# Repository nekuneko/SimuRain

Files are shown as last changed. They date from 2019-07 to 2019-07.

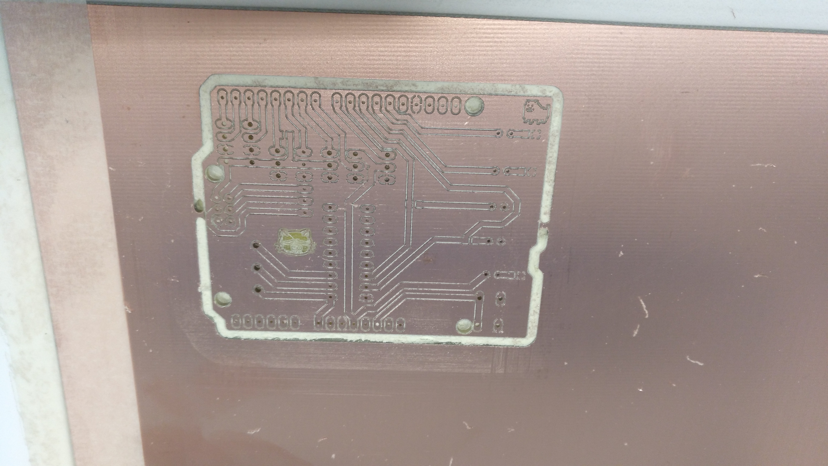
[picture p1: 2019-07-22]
Documentación/Fotos/IMG_20181212_210651_355.jpg

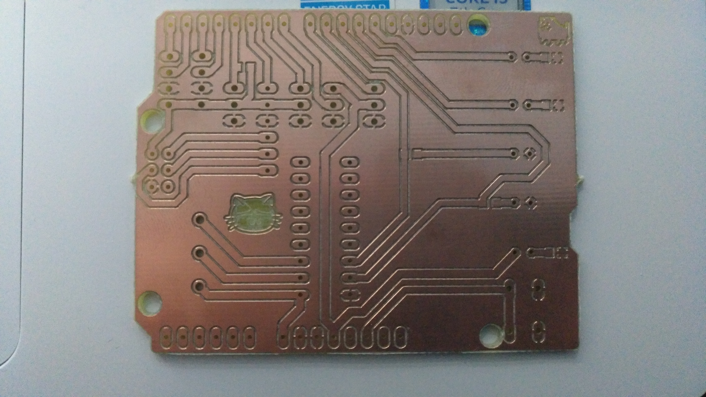
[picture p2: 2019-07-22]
Documentación/Fotos/IMG_20181212_230534_652.jpg

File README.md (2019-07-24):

## Instructions (Work in progress...)

The system currently works following the flow:

* The program is loaded into the ROM of the card and gets activated when receives electric power and the serial port is opened.

* When running, the program writes every 2 second the data received from the different sensors. So running the Arduino IDE showing the serial port is recommended. This information is needed firstly to calibrate the instruments of the experiment.

* Software records day-time, Ph and temperature every two seconds.

* The output file is "datalog.txt", but it can be modified in the source code. It includes Windows CRLF, in UTF-8 format.

* Every time new data is recorded in the microSD card, the modification date of the file in the operating system is modified.

* New data is appended at the end of the file. If user needs data separated into different files, (s)he has to do it manually.

Troubleshooting:

* In case of problems when writing in the card, formatting the SD card with the "SD Card Formatter" software is recommended: https://www.sdcard.org/downloads/formatter_4/index.html

* In case the time is not synchronized (or too early/delayed) it can be re-adjusted: disconnect electric power, take the batteries off using a screwdriver and, after 10 seconds, connect it again and load the program anew. The system, when the serial port will be opened, will detect that there is no actual time and will use the compilation time of the program as current time.

## Instrucciones provisionales (Work in progress...)

El programa actualmente funciona de la siguiente manera:

* El programa se carga en la ROM de la tarjeta y se activa cuando recibe alimentación y se abre el puerto serial. En el puerto serial se van mostrando las lecturas y otra información, por lo que hace falta tener e Arduino IDE y mostrar el puerto serial. Esta información puede servir para la calibración del experimento.

* El software registra dia-hora, Ph y temperatura (no caudal), espera hasta que terminen de pasar 2 segundos y vuelve a hacerlo.

* El nombre del fichero de salida es "datalog.txt", su puede cambiar al inicio del programa. El fichero tiene final de línea Windows CRLF, codificado en UTF-8.

* Cuando se escribe en la tarjeta microSD, se guarda la fecha de modificación de la última vez que fue escrita.

* El contenido se añade al final del fichero. Si se desean separar los datos hay que hacerlo a mano desde el ordenador.

En caso de problemas:

* Si hay problemas de escritura se debe probar a formatear la tarjeta microSD con el software "SD Card Formatter": https://www.sdcard.org/downloads/formatter_4/index.html

* Si se pierde la hora (o el reloj atrasa/adelanta más de lo deseado) se puede ajustar la hora. Para hacerlo se desconecta todo de la alimentación eléctrica, se saca la pila con un destornillador, se esperan 10 segundos, se vuelve a conectar y se vuelve a subir el programa. El sistema, cuando se abra el puerto serial, detectará que no tiene horay cogerá la hora de la última compilación del programa como hora actual para desde ahí empezará a contar.

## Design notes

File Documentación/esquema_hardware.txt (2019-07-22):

El esquema comienza con dos mangueras numeradas 1 (izquierda) y 2 (derecha) que suponen la entrada de líquidos al sistema, cada una controlada con un relé o electroválvula.

El agua se mezcla en una "T" y pasa por el medidor de caudal (caudalímetro), medido de Ph y medidor de temperatura, en ese orden, antes de salir por la alcachofa de la ducha.

Todo está conectado a una placa Arduino Leonardo (parece que la Arduino UNO tiene una memoria insuficiente para el software que necesitamos ejecutar). Sobre esa placa hay una placa de conexión que redirige los pines a los sensores correspondientes. El conexionado actual es el siguiente (NC es No Conectado, no se usa). A veces se indica uso distinto si fuera Leonardo o UNO:

 // Pin configuration
 // Note: By default relays are connected to 12v, so they are CLOSED and they don't permit water flow.
 // pinMode(A5, NC);                  // A5 - Arduino UNO: I2C SCL; Arduino Leonardo: NC
 // pinMode(A4, NC);                  // A4 - Arduino UNO: I2C SDA; Arduino Leonardo: NC
 // pinMode(A3, NC);                  // A3 
 // pinMode(A2, NC);                  // A2 
 // pinMode(A1, NC);                  // A1 
 // pinMode(13, NC);                  // D13                Arduino UNO: SPI SCK;  Arduino Leonardo: NC
    pinMode(PIN_LED_INFO,   OUTPUT);  // D12 - LED INFO     Arduino UNO: SPI MISO; Arduino Leonardo: NC
    pinMode(PIN_LED_STATUS, OUTPUT);  // D11 - LED STATUS   Arduino UNO: SPI MOSI; Arduino Leonardo: NC
    pinMode(PIN_RELAY_1,    OUTPUT);  // D10 - Relay 8B -> ULN2803A Darlington Transistor Array -> 8C -> RIGHT RELAY, WATER INPUT 2: HIGH OPEN; LOW CLOSED
    pinMode(PIN_RELAY_2,    OUTPUT);  // D9  - Relay 7B -> ULN2803A Darlington Transistor Array -> 7C -> LEFT  RELAY, WATER INPUT 1: HIGH OPEN; LOW CLOSED
    pinMode(PIN_SENSOR_AUX,  INPUT);  // D8  - (A8) Sensor: AUX
    pinMode(PIN_SENSOR_FLOW, INPUT_PULLUP);  // D7 - Sensor: Flow (INTERRUPT)
    pinMode(PIN_SENSOR_PH,   INPUT);  // D6 - (A7)Sensor: PH   
 // pinMode(PIN_SDCARD_SS,  OUTPUT);  // D5 - SPI Chipselect: MicroSD, initialized on SD begin function.
 // pinMode(PIN_SENSOR_TEMP, INPUT);  // D4 - (A6) Sensor: Temp, initialized on DS18B20 constructor. 
 // pinMode(3,  NC);                  // D3 - Arduino Leonardo: I2C SCL  
 // pinMode(2,  NC);                  // D2 - Arduino Leonardo: I2C SDA  
 // pinMode(1,  NC);                  // D1 - Arduino Leonardo: Serial1 
 // pinMode(0,  NC);                  // D0 - Arduino Leonardo: Serial1

La interfaz hardware del sistema muestra 5 leds:

	* SISTEMA ENCENDIDO: Este led indica que el sistema está encendido y siempre se iluminará al conectar la alimentación.
	* ENTRADA DE AGUA 1: Este led se iluminará cuando se encuentre abierta la entrada de agua número 1 (izquierda).
	* ENTRADA DE AGUA 2: Este led se iluminará cuando se encuentre abierta la entrada de agua número 2 (derecha).
	* ESTADO: Por determinar, si el arranque va bien se iluminará.
	* INFO: Por determinar, si el arranque es correcto se iluminará.

Dispone de un botón RESET para reiniciar el sistema en lugar de tener que desenchufar la placa y volverla a enchufar.

Medida del caudal:
El caudal se mide por interrupciones, durante un segundo, se leen cuantas vueltas ha realizado el sensor de efecto hall del caudalímetro.

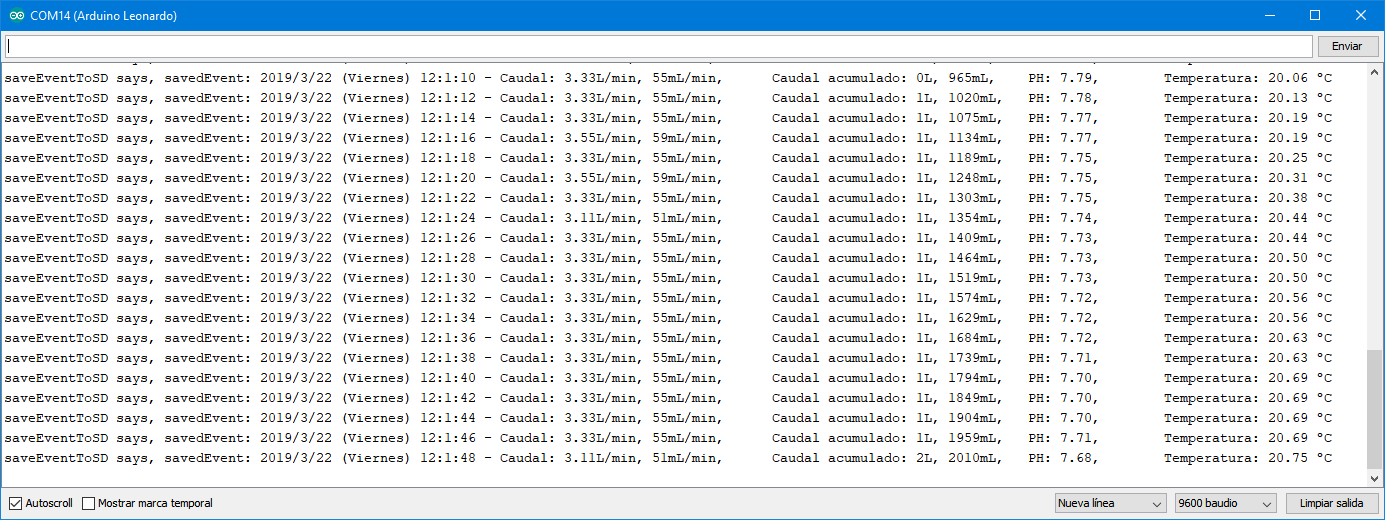
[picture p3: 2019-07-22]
Documentación/Datos recabados/datosLluvia.PNG

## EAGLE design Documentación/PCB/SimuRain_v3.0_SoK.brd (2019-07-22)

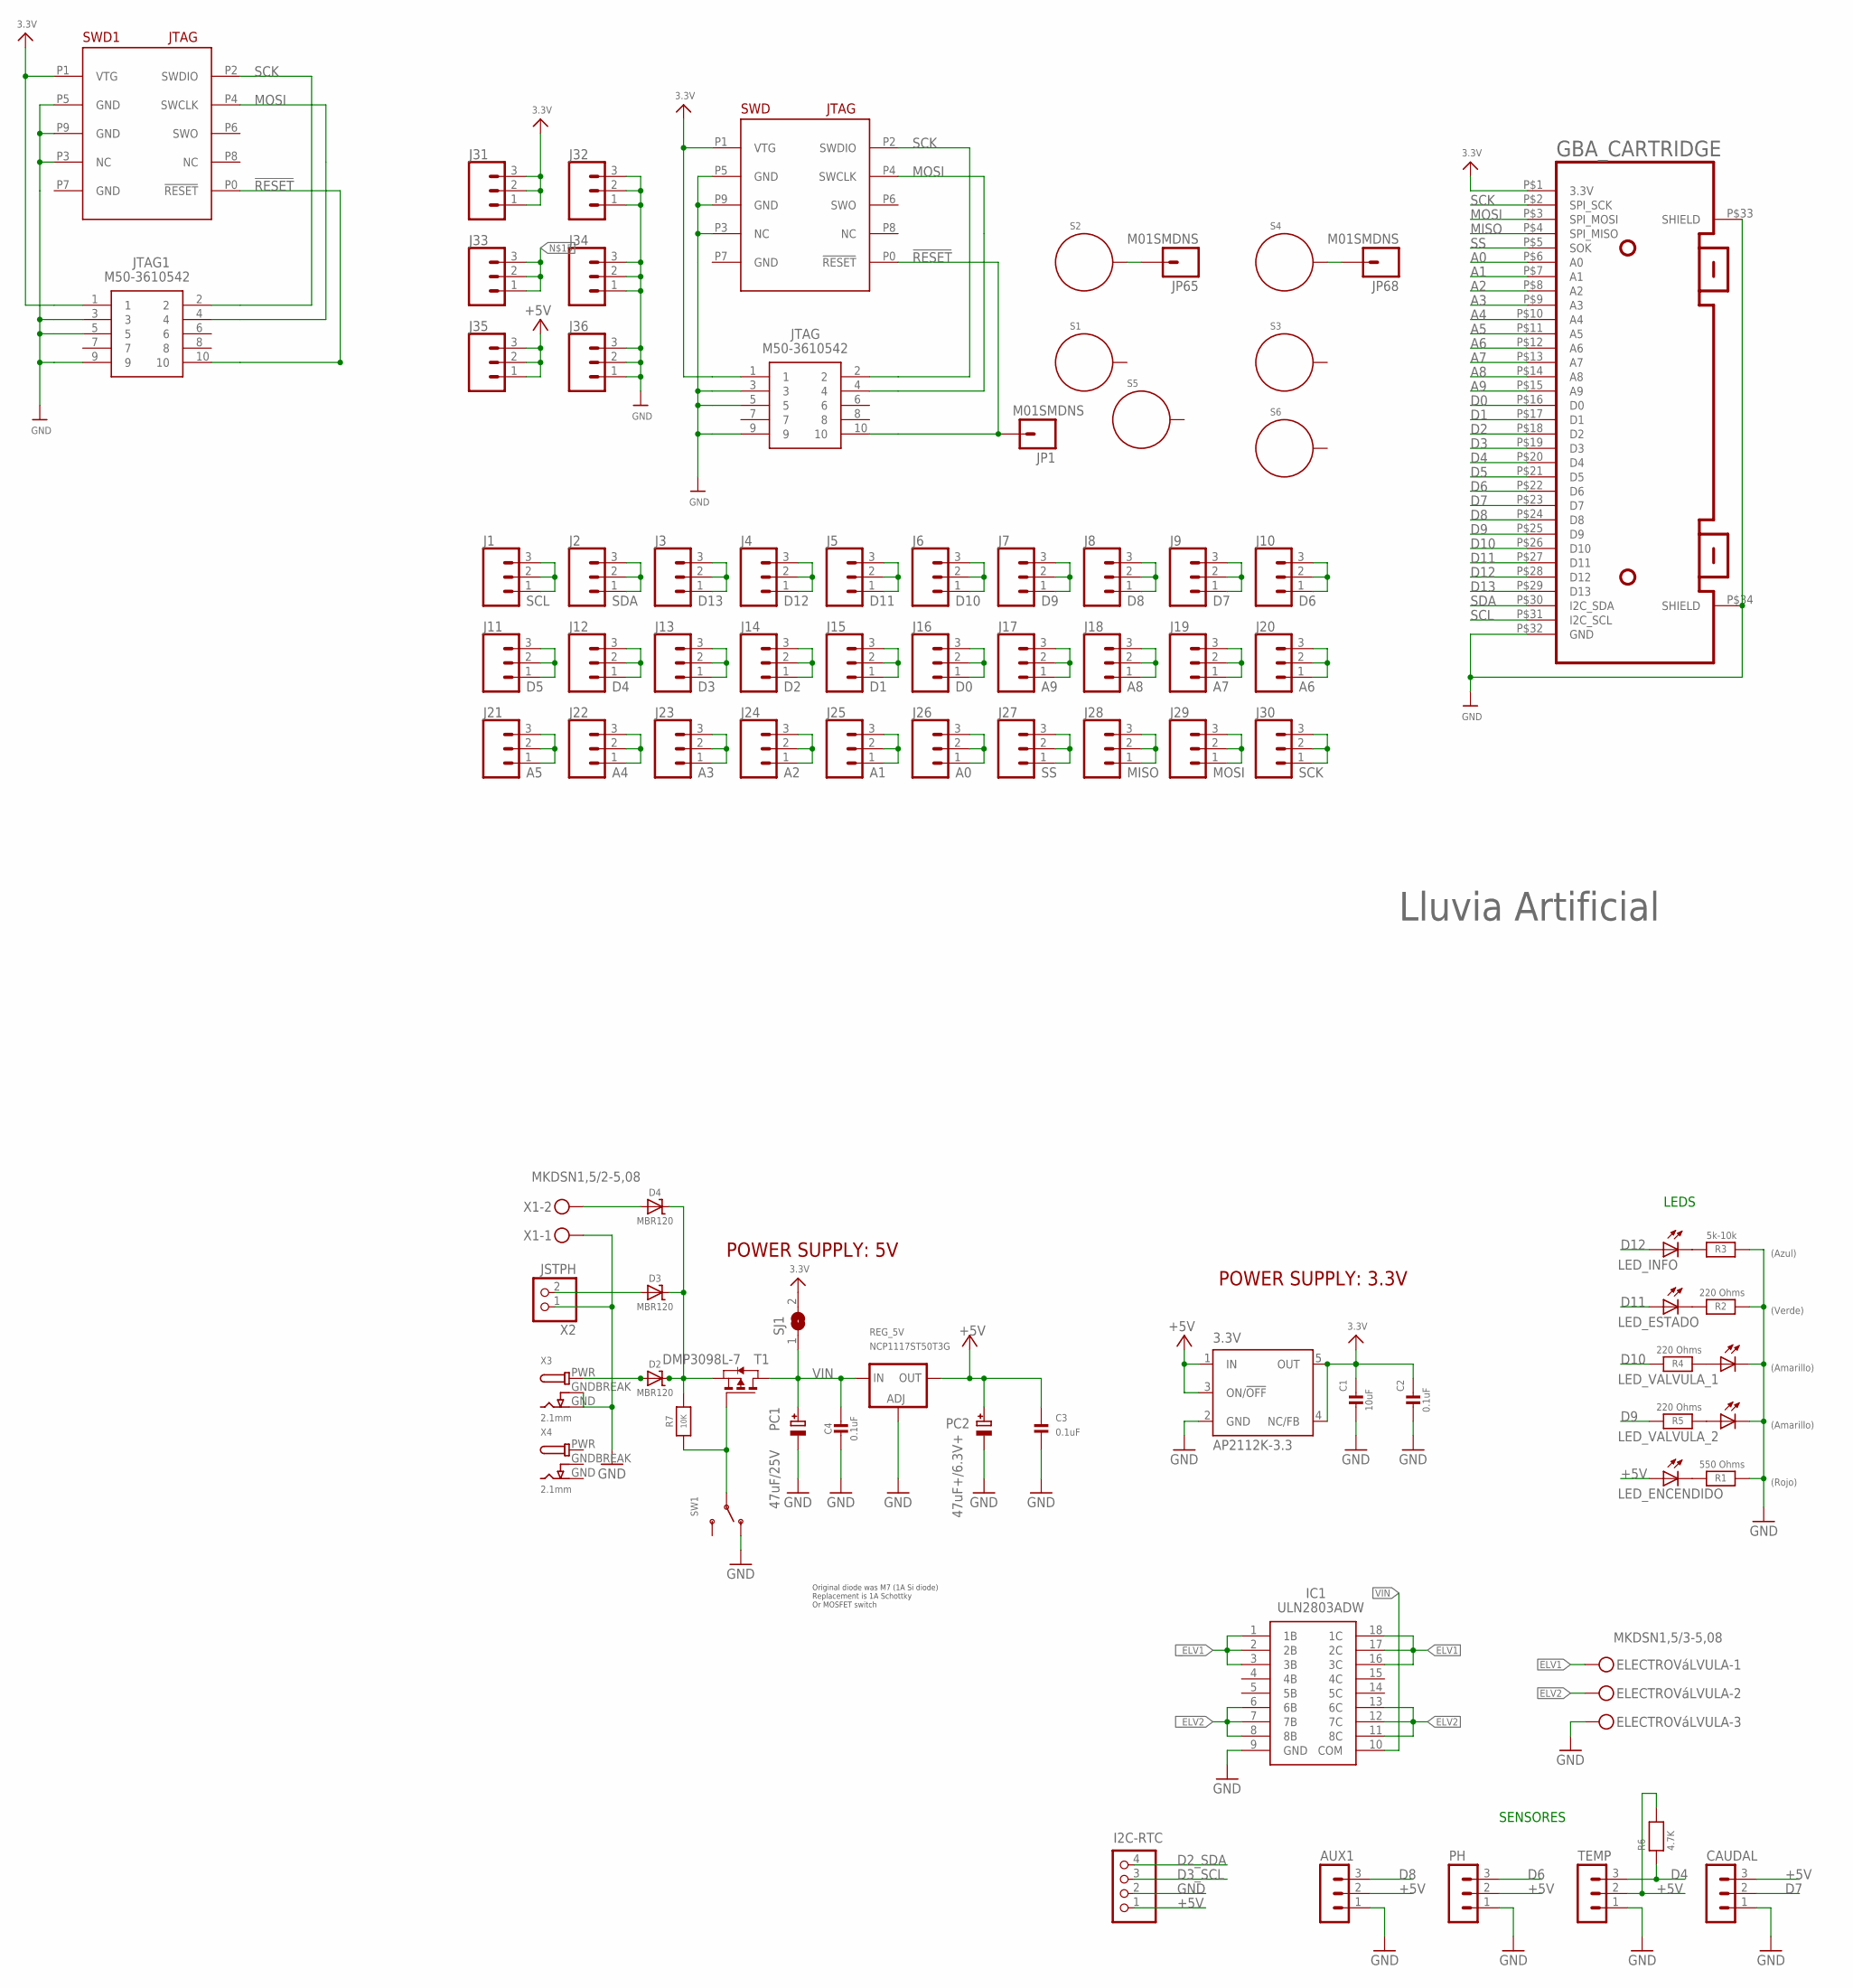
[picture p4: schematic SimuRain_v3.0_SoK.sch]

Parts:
3.3V: AP2112K-3.3; SOT23-DBV
AUX1: MA03-1
C1: 10uF; _0603
C2, C3, C4: 0.1uF; _0603
CAUDAL: MA03-1
D2, D3, D4: MBR120; SOD-123
ELECTROVáLVULA: MKDSN1,5/3-5,08
GBA_CARTRIDGE: GBA_CARTRIDGEGBA_CARTRIDGE2; GBA_CARTRIDGE2
I2C-RTC: HEADER-1X4; 1X04_OVAL
IC1: ULN2803ADW; SOIC127P1030X265-18N
J1, J2, J3, J4, J5, J6, J7, J8, J9, J10, J11, J12, J13, J14, J15, J16, J17, J18, J19, J20, J21, J22, J23, J24, J25, J26, J27, J28, J29, J30, J31, J32, J33, J34, J35, J36: CONN_031X03_NO_SILK; 1X03_NO_SILK
JP1, JP65, JP68: M01SMDNS; 1X01NS
JTAG, JTAG1: M50-3610542; M503610542
LED_ENCENDIDO: LED5MM
LED_ESTADO: LED5MM
LED_INFO: LED5MM
LED_VALVULA_1, LED_VALVULA_2: LED5MM
PC1: 47uF/25V; PANASONIC_D
PC2: 47uF+/6.3V+; PANASONIC_D
PH: MA03-1
R1: 550 Ohms; _0805
R2, R4, R5: 220 Ohms; _0805
R3: 5k-10k; _0805
R6: 4.7K; _0805
R7: 10K; _0805
REG_5V: NCP1117ST50T3G; SOT223-R
S1, S2, S3, S4, S5, S6: STANDOFF_ELECTRICAL; STANDOFF-ELECTRICAL
SJ1: SOLDERJUMPERREFLOW_NOPASTE; SOLDERJUMPER_REFLOW_NOPASTE
SW1: SWITCH_SPDT; SPDT_SMT_SSSS811101
SWD, SWD1: JTAGICE3-CONNECTOR50MIL-THT; JTAGICE3-50MIL
T1: DMP3098L-7; SOT-23
TEMP: MA03-1
X1: MKDSN1,5/2-5,08
X2: JSTPH; JSTPH2
X3, X4: 2.1mm; DCJACK_2MM_PTH

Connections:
3.3V: 3.3V.4 (NC/FB), 3.3V.5 (OUT), C1.1, C2.1, GBA_CARTRIDGE.P$1 (3.3V), J31.1, J31.2, J31.3, JTAG.1, JTAG1.1, SJ1.2, SWD.P1 (VTG), SWD1.P1 (VTG)
!RESET: JP1.1, JTAG.10, JTAG1.10, SWD.P0 (!RESET), SWD1.P0 (!RESET)
+5V: 3.3V.1 (IN), 3.3V.3 (ON/!OFF), AUX1.2, C3.1, CAUDAL.3, I2C-RTC.1, J35.1, J35.2, J35.3, LED_ENCENDIDO.A, PC2.+, PH.2, R6.2, REG_5V.2 (OUT), REG_5V.4 (OUT), TEMP.2
A0: GBA_CARTRIDGE.P$6 (A0), J26.1, J26.2, J26.3
A1: GBA_CARTRIDGE.P$7 (A1), J25.1, J25.2, J25.3
A2: GBA_CARTRIDGE.P$8 (A2), J24.1, J24.2, J24.3
A3: GBA_CARTRIDGE.P$9 (A3), J23.1, J23.2, J23.3
A4: GBA_CARTRIDGE.P$10 (A4), J22.1, J22.2, J22.3
A5: GBA_CARTRIDGE.P$11 (A5), J21.1, J21.2, J21.3
A6: GBA_CARTRIDGE.P$12 (A6), J20.1, J20.2, J20.3
A7: GBA_CARTRIDGE.P$13 (A7), J19.1, J19.2, J19.3
A8: GBA_CARTRIDGE.P$14 (A8), J18.1, J18.2, J18.3
A9: GBA_CARTRIDGE.P$15 (A9), J17.1, J17.2, J17.3
D0: GBA_CARTRIDGE.P$16 (D0), J16.1, J16.2, J16.3
D1: GBA_CARTRIDGE.P$17 (D1), J15.1, J15.2, J15.3
D2: GBA_CARTRIDGE.P$18 (D2), J14.1, J14.2, J14.3
D2_SDA: I2C-RTC.4
D3: GBA_CARTRIDGE.P$19 (D3), J13.1, J13.2, J13.3
D3_SCL: I2C-RTC.3
D4: GBA_CARTRIDGE.P$20 (D4), J12.1, J12.2, J12.3, R6.1, TEMP.3
D5: GBA_CARTRIDGE.P$21 (D5), J11.1, J11.2, J11.3
D6: GBA_CARTRIDGE.P$22 (D6), J10.1, J10.2, J10.3, PH.3
D7: CAUDAL.2, GBA_CARTRIDGE.P$23 (D7), J9.1, J9.2, J9.3
D8: AUX1.3, GBA_CARTRIDGE.P$24 (D8), J8.1, J8.2, J8.3
D9: GBA_CARTRIDGE.P$25 (D9), J7.1, J7.2, J7.3, R5.1
D10: GBA_CARTRIDGE.P$26 (D10), J6.1, J6.2, J6.3, R4.1
D11: GBA_CARTRIDGE.P$27 (D11), J5.1, J5.2, J5.3, LED_ESTADO.A
D12: GBA_CARTRIDGE.P$28 (D12), J4.1, J4.2, J4.3, LED_INFO.A
D13: GBA_CARTRIDGE.P$29 (D13), J3.1, J3.2, J3.3
ELV1: ELECTROVáLVULA.1, IC1.16 (3C), IC1.17 (2C), IC1.18 (1C)
ELV2: ELECTROVáLVULA.2, IC1.11 (8C), IC1.12 (7C), IC1.13 (6C)
GND: 3.3V.2 (GND), AUX1.1, C1.2, C2.2, C3.2, C4.2, CAUDAL.1, ELECTROVáLVULA.3, GBA_CARTRIDGE.P$32 (GND), GBA_CARTRIDGE.P$33 (SHIELD), GBA_CARTRIDGE.P$34 (SHIELD), I2C-RTC.2, IC1.9 (GND), J32.1, J32.2, J32.3, J34.1, J34.2, J34.3, J36.1, J36.2, J36.3, JTAG.3, JTAG.5, JTAG.9, JTAG1.3, JTAG1.5, JTAG1.9, LED_VALVULA_1.K (C), LED_VALVULA_2.K (C), PC1.-, PC2.-, PH.1, R1.2, R2.2, R3.2, REG_5V.1 (ADJ), SW1.A (O), SWD.P3 (NC), SWD.P5 (GND), SWD.P9 (GND), SWD1.P3 (NC), SWD1.P5 (GND), SWD1.P9 (GND), TEMP.1, X1.1, X2.1, X3.GND, X3.GNDBREAK, X4.GND
GNDBREAK: X4.GNDBREAK
MISO: GBA_CARTRIDGE.P$4 (SPI_MISO), J28.1, J28.2, J28.3
MOSI: GBA_CARTRIDGE.P$3 (SPI_MOSI), J29.1, J29.2, J29.3, JTAG.4, JTAG1.4, SWD.P4 (SWCLK), SWD1.P4 (SWCLK)
unnamed: D4.A, X1.2
unnamed: D3.A, X2.2
unnamed: LED_ENCENDIDO.K (C), R1.1
unnamed: LED_ESTADO.K (C), R2.1
unnamed: LED_INFO.K (C), R3.1
unnamed: LED_VALVULA_2.A, R5.2
unnamed: LED_VALVULA_1.A, R4.2
unnamed: D2.C, D3.C, D4.C, J33.1, J33.2, J33.3, R7.2, T1.2 (S)
unnamed: JP65.1, S2.P1
unnamed: JP68.1, S4.P1
PWR: X4.PWR
PWRIN: D2.A, X3.PWR
PWR_SWITCH: R7.1, SW1.B, T1.3 (G)
SCK: GBA_CARTRIDGE.P$2 (SPI_SCK), J30.1, J30.2, J30.3, JTAG.2, JTAG1.2, SWD.P2 (SWDIO), SWD1.P2 (SWDIO)
SCL: GBA_CARTRIDGE.P$31 (I2C_SCL), J1.1, J1.2, J1.3
SDA: GBA_CARTRIDGE.P$30 (I2C_SDA), J2.1, J2.2, J2.3
SS: GBA_CARTRIDGE.P$5 (SOK), J27.1, J27.2, J27.3
VIN: C4.1, IC1.10 (COM), PC1.+, REG_5V.3 (IN), SJ1.1, T1.1 (D)
_ELV1: IC1.1 (1B), IC1.2 (2B), IC1.3 (3B)
_ELV2: IC1.6 (6B), IC1.7 (7B), IC1.8 (8B)

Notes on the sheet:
Lluvia Artificial
Original diode was M7 (1A Si diode) Replacement is 1A Schottky Or MOSFET switch
POWER SUPPLY: 5V
POWER SUPPLY: 3.3V
SENSORES
LEDS
(Azul)
(Verde)
(Amarillo)
(Rojo)

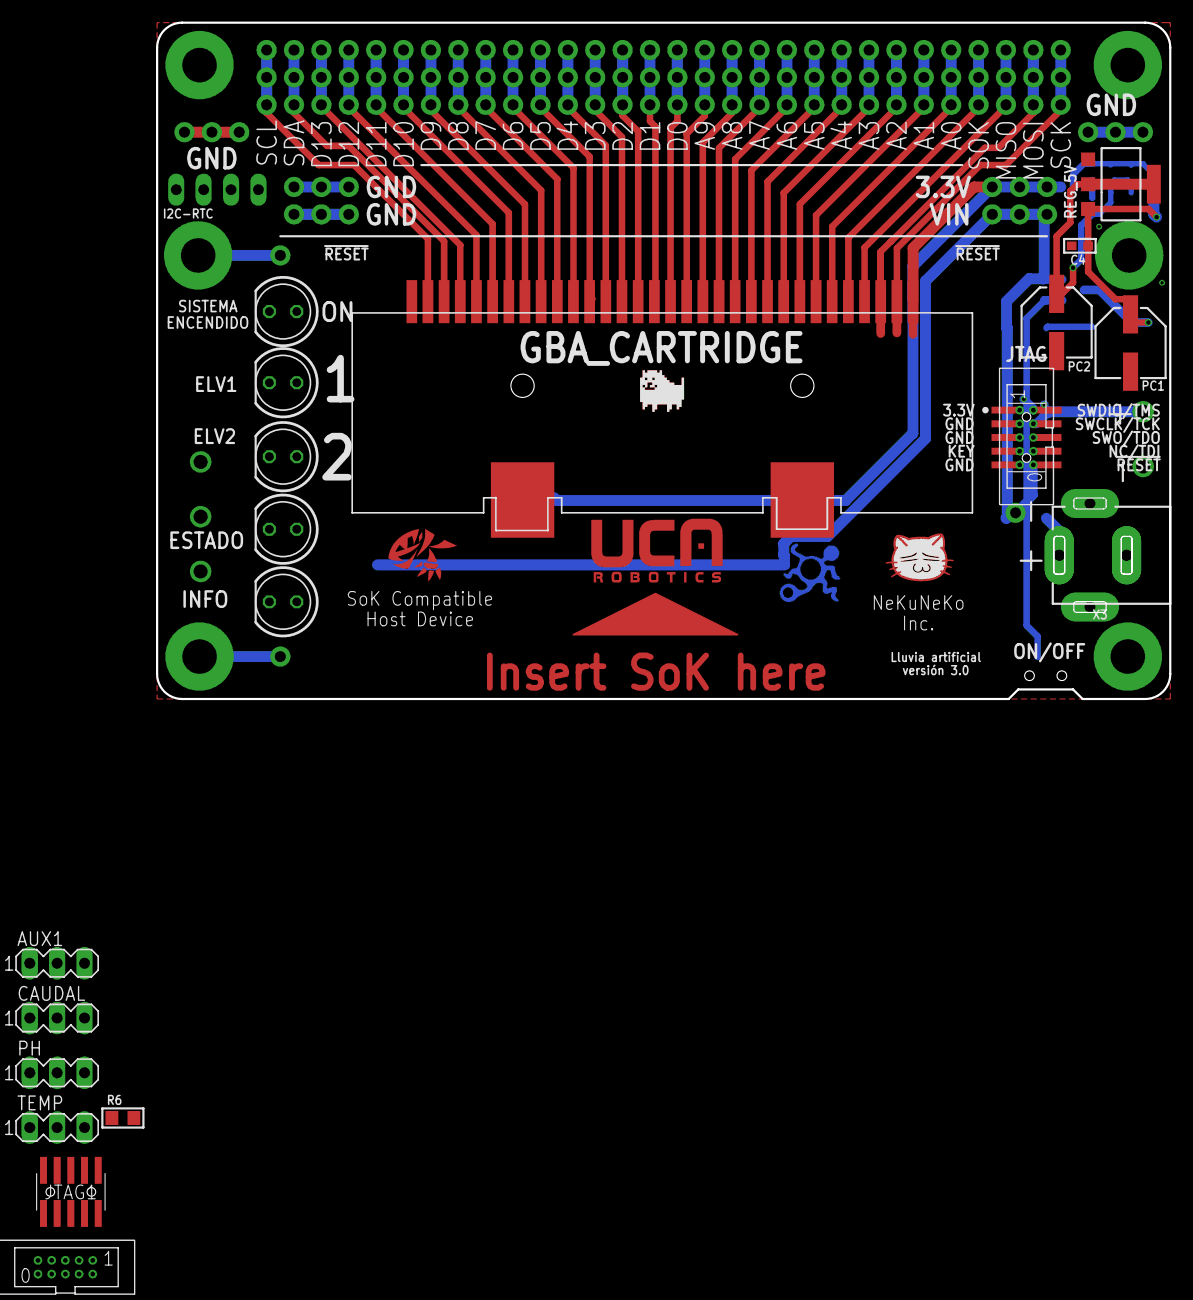
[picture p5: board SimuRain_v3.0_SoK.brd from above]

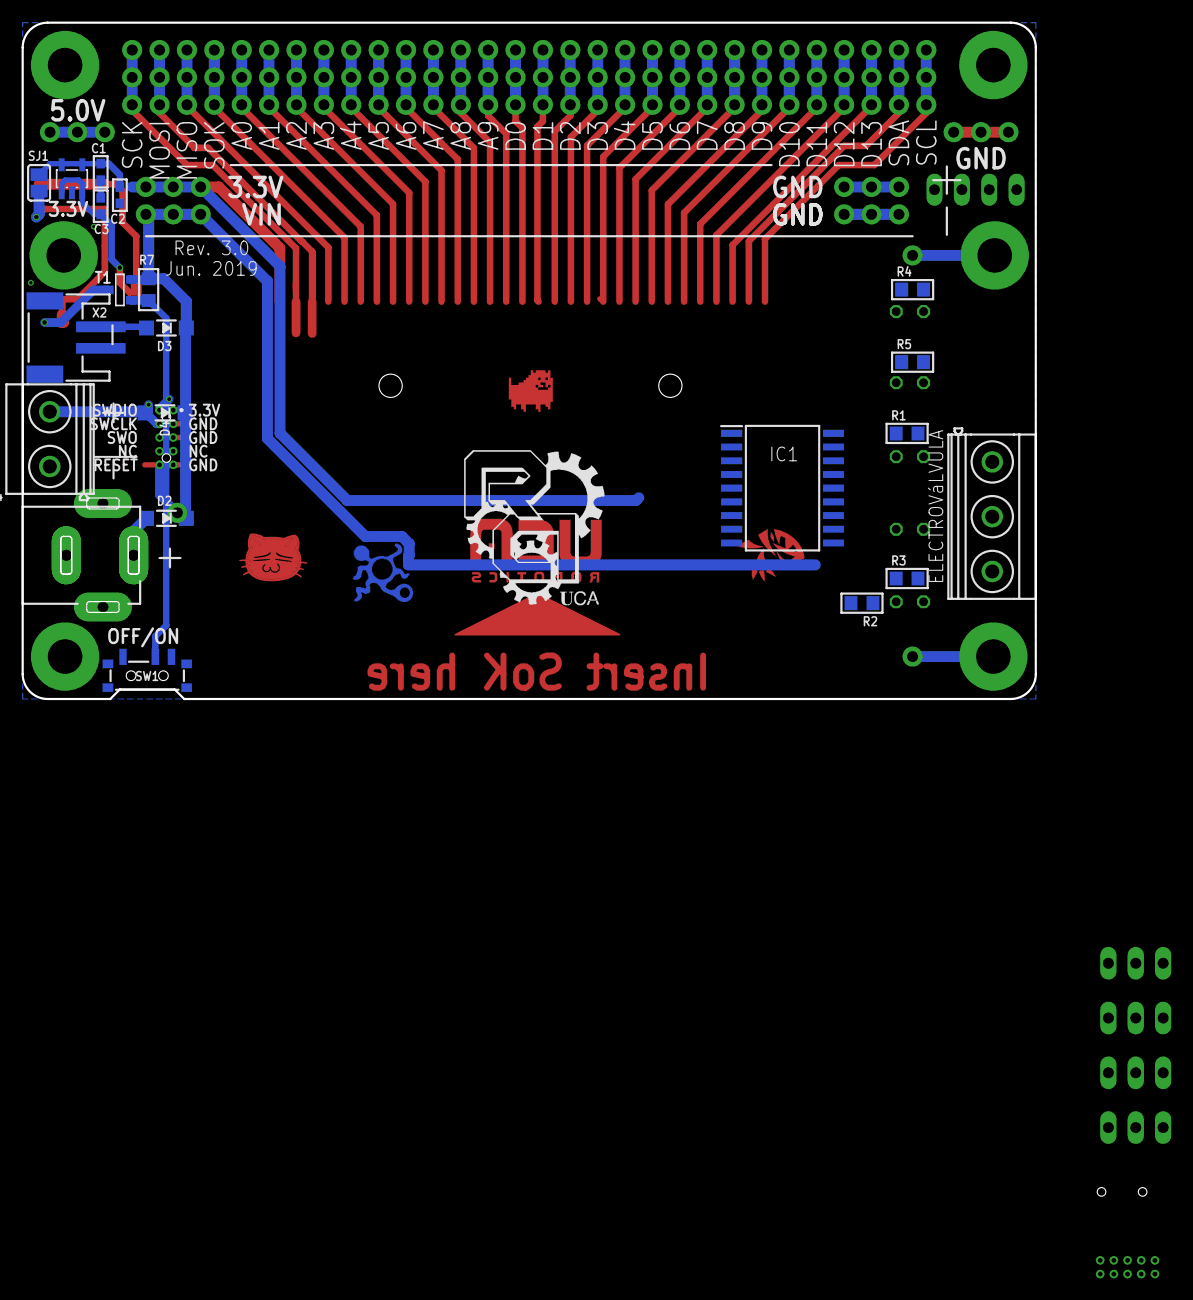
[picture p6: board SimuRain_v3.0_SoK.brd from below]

Board: 2 copper layers, 94.0 x 62.7 mm, 94 parts (57 on the bottom side), 51 nets.

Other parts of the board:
U$1: NEKO_6_5_BORDE_TPLACE
U$2: DOG
U$3: SOK_FINISH
U$9: GIRA
U$10: UCAROBOTICS
U$15: BUGS_6
U$50: TRIANGLE

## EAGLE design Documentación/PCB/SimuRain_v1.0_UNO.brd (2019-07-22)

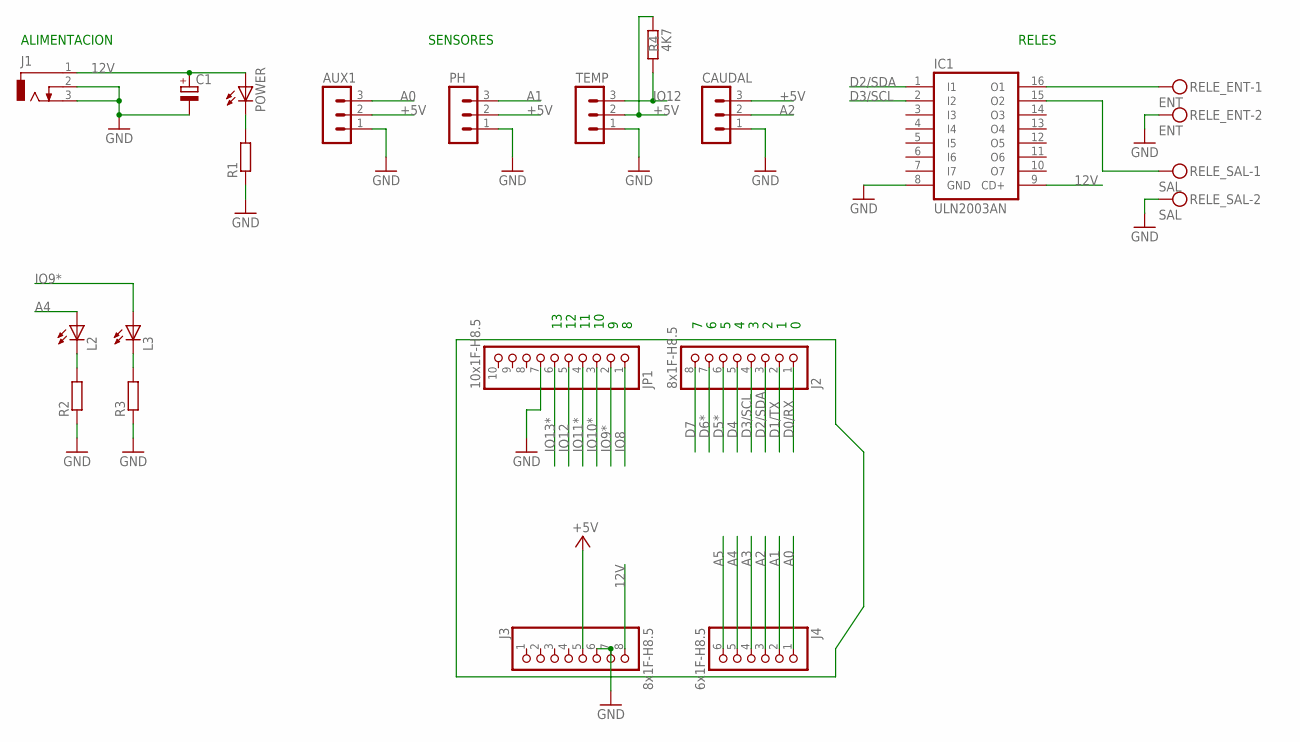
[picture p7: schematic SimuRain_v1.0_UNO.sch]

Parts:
AUX1: MA03-1
C1: CPOL-EUE5-6; E5-6
CAUDAL: MA03-1
IC1: ULN2003AN; DIL16
J1: DCJ0303
J2, J3: 8x1F-H8.5; 1X08
J4: 6x1F-H8.5; 1X06
JP1: 10x1F-H8.5; 1X10
L2, L3: LED5MM
PH: MA03-1
POWER: LED5MM
R1, R2, R3: R-EU_0204/5; 0204/5
R4: 4K7; 0204/5
RELE_ENT: ENT; MKDSN1,5/2-5,08
RELE_SAL: SAL; MKDSN1,5/2-5,08
TEMP: MA03-1

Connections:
12V: C1.+, IC1.9 (CD+), J1.1, J3.8, POWER.A
+5V: AUX1.2, CAUDAL.3, J3.5, PH.2, R4.2, TEMP.2
A0: AUX1.3, J4.1
A1: J4.2, PH.3
A2: CAUDAL.2, J4.3
A3: J4.4
A4: J4.5, L2.A
A5: J4.6
D0/RX: J2.1
D1/TX: J2.2
D2/SDA: IC1.1 (I1), J2.3
D3/SCL: IC1.2 (I2), J2.4
D4: J2.5
D5*: J2.6
D6*: J2.7
D7: J2.8
GND: AUX1.1, C1.-, CAUDAL.1, IC1.8 (GND), J1.2, J1.3, J3.6, J3.7, JP1.7, PH.1, R1.1, R2.1, R3.1, RELE_ENT.2, RELE_SAL.2, TEMP.1
IO8: JP1.1
IO9*: JP1.2, L3.A
IO10*: JP1.3
IO11*: JP1.4
IO12: JP1.5, R4.1, TEMP.3
IO13*: JP1.6
unnamed: IC1.16 (O1), RELE_ENT.1
unnamed: IC1.15 (O2), RELE_SAL.1
unnamed: L2.K (C), R2.2
unnamed: L3.K (C), R3.2
unnamed: POWER.K (C), R1.2

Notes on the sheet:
ALIMENTACION
SENSORES
RELES

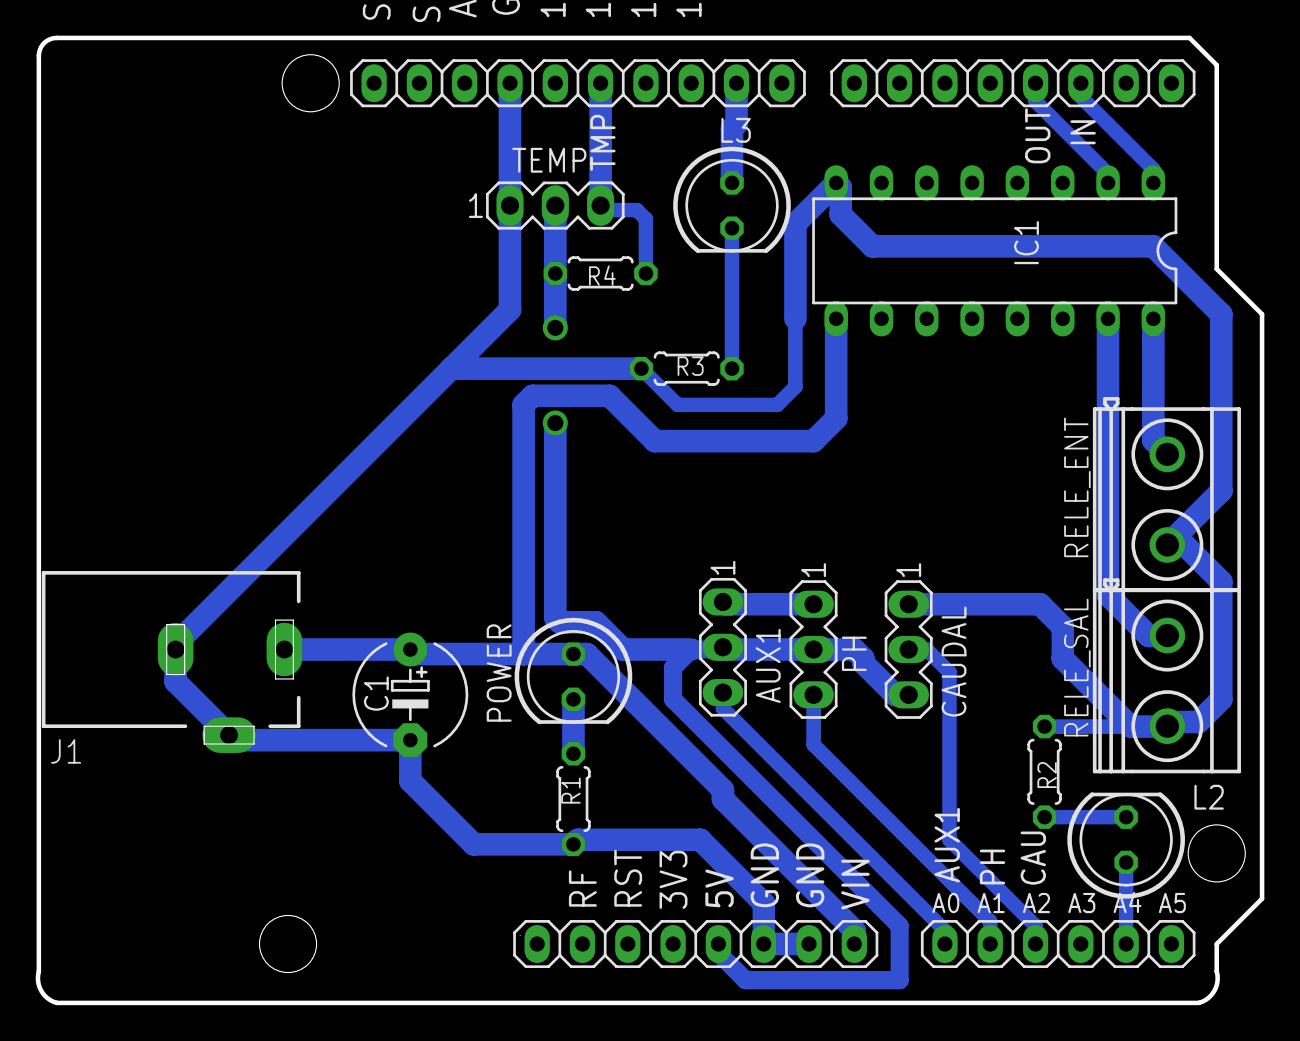
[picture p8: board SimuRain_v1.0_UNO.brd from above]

Board: 2 copper layers, 68.6 x 54.1 mm, 20 parts (0 on the bottom side), 16 nets.

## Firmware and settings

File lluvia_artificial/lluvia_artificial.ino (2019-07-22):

// This code needs an Almoraima v2.x board installed on an Arduino Leonardo
// Author: Javier Villaverde Ramallo
// Date:   2018.12.20
#include <Wire.h>     // I2C comunication
#include <SPI.h>      // SPI comunication
#include <SD.h>       // <---- Standard Library Embedded in Arduino. File > Examples > SD (Archivo > Ejemplos > SD).
#include <RTClib.hpp> // Library by @gutierrezps https://github.com/gutierrezps/RTClib mod of Adafruit's https://learn.adafruit.com/adafruit-ds3231-precision-rtc-breakout/overview
                      // This RTC library allow compare dates.
#include <cactus_io_DS18B20.h> // Adafruit Prewired Temperature DS18B20 Sensor. For hookup details using this sensor then visit
                               // http://cactus.io/hookups/sensors/temperature-humidity/ds18b20/hookup-arduino-to-ds18b20-temperature-sensor 

// Global constants
#define mySerial        Serial    // Switchs between Serial (USB) / Serial1 (Bluetooth) to print data
#define RELAY1_STATUS   HIGH      // HIGH Abierto, LOW Cerrado
#define RELAY2_STATUS   LOW       // HIGH Abierto, LOW Cerrado

// save measures every....
const int16_t everyDays    = 0;
const int8_t  everyMinutes = 0;
const int8_t  everyHours   = 0;
const int8_t  everySeconds = 2;

const String fileName = "datalog.txt";      // Name of the file Where register the Event.
const float  flowCalibrationFactor = 4.5;   // Sensor: Flow, calibration. The hall-effect flow sensor outputs approximately 4.5 pulses per second per litre/minute of flow.

const String daysOfTheWeek[7] = {"Domingo", "Lunes", "Martes", "Miércoles", "Jueves", "Viernes", "Sábado"}; // For Date

// Pin definitions
// Note: By default relays are connected to 12v, so they are CLOSED and they don't permit water flow.
//      PIN_LED_POWER   +5V   // ALWAYS ON
#define PIN_LED_INFO    12    // OUTPUT: INFO LED,   HIGH ON, LOW OFF 
#define PIN_LED_STATUS  11    // OUTPUT: STATUS LED, HIGH ON, LOW OFF 
#define PIN_RELAY_1     10    // OUTPUT: LEFT  RELAY, WATER INPUT 1: HIGH OPEN; LOW CLOSED
#define PIN_RELAY_2     9     // OUTPUT: RIGHT RELAY, WATER INPUT 2: HIGH OPEN; LOW CLOSED
#define PIN_SENSOR_AUX  A8    // INPUT: A8 (D8). Aux sensor analog input for future use.
#define PIN_SENSOR_FLOW 7     // INPUT_PULLUP:  Flow sensor interrupt pin. 
#define PIN_SENSOR_PH   A7    // INPUT: A7 (D6).       pH meter v1.1 sensor Analog output to Arduino Analog Input A7 on Digital pin 6
#define PIN_SDCARD_SS   5     // OUTPUT: microSD card's chip select
#define PIN_SENSOR_TEMP A6    // INPUT: A6 (D4). DS18S20 temperature sensor Analog output to Arduino Analog Input A6 on Digital pin 4
//      I2C_SCL_RTC     3     // I2C communicatin for Real Time Clock 
//      I2C_SDA_RTC     2     // I2C communicatin for Real Time Clock
//      SERIAL1_TX      1     // Serial1 Bluetooth Communication
//      SERIAL2_RX      0     // Serial1 Bluetooth Communication
// SPI_MISO_MICRO_SD    MISO  // SPI communication for Micro SD
// SPI_MOSI_MICRO_SD    MOSI  // SPI communication for Micro SD
// SPI_SCK_MICRO_SD     SCK   // SPI communication for Micro SD      



// Global variables
DS18B20 ds(PIN_SENSOR_TEMP);    // Sensor: Temperature class
RTC_DS3231 rtc;                 // Sensor: RTC class
DateTime now;                   // Time: now
DateTime future;                // Time: Timestamp in the future



volatile byte flowPulseCount;   // Sensor: Flow, interruption counter.
float flowRate;                 // Sensor: Flow, litres per minute
unsigned int flowMilliLitres;   // Sensor: Flow, mililitres per mitute
unsigned long totalMilliLitres; // Sensor: Flow, accumulated millilitres


// Interrupt Service Routine for Flow Sensor
void flowPulseCounter ()
{
  ++flowPulseCount; // Increment global pulse counter variable
}


// Blinks a led for a duration milliseconds period
void blink (int pin, int duration)
{
  digitalWrite(pin, HIGH);
  delay(duration);
  
  digitalWrite(pin, LOW);
  delay(duration);
}


void setup() 
{
  // Opens Serial USB
    mySerial.begin(9600);
    //while(!mySerial) // Wait until serial opens, comment to not to wait at startup
      //blink(PIN_LED_INFO, 1000);
    mySerial.println("lluvia_artificial.ino");
   
 // Pin configuration
 // Note: By default relays are connected to 12v, so they are CLOSED and they don't permit water flow.
 // pinMode(A5, NC);                  // A5 - Arduino UNO: I2C SCL; Arduino Leonardo: NC
 // pinMode(A4, NC);                  // A4 - Arduino UNO: I2C SDA; Arduino Leonardo: NC
 // pinMode(A3, NC);                  // A3 
 // pinMode(A2, NC);                  // A2 
 // pinMode(A1, NC);                  // A1 
 // pinMode(13, NC);                  // D13                Arduino UNO: SPI SCK;  Arduino Leonardo: NC
    pinMode(PIN_LED_INFO,   OUTPUT);  // D12 - LED INFO     Arduino UNO: SPI MISO; Arduino Leonardo: NC
    pinMode(PIN_LED_STATUS, OUTPUT);  // D11 - LED STATUS   Arduino UNO: SPI MOSI; Arduino Leonardo: NC
    pinMode(PIN_RELAY_1,    OUTPUT);  // D10 - Relay 8B -> ULN2803A Darlington Transistor Array -> 8C -> RIGHT RELAY, WATER INPUT 2: HIGH OPEN; LOW CLOSED
    pinMode(PIN_RELAY_2,    OUTPUT);  // D9  - Relay 7B -> ULN2803A Darlington Transistor Array -> 7C -> LEFT  RELAY, WATER INPUT 1: HIGH OPEN; LOW CLOSED
    pinMode(PIN_SENSOR_AUX,  INPUT);  // D8  - (A8) Sensor: AUX
    pinMode(PIN_SENSOR_FLOW, INPUT_PULLUP);  // D7 - Sensor: Flow (INTERRUPT)
    pinMode(PIN_SENSOR_PH,   INPUT);  // D6 - (A7)Sensor: PH   
 // pinMode(PIN_SDCARD_SS,  OUTPUT);  // D5 - SPI Chipselect: MicroSD, initialized on SD begin function.
 // pinMode(PIN_SENSOR_TEMP, INPUT);  // D4 - (A6) Sensor: Temp, initialized on DS18B20 constructor. 
 // pinMode(3,  NC);                  // D3 - Arduino Leonardo: I2C SCL  
 // pinMode(2,  NC);                  // D2 - Arduino Leonardo: I2C SDA  
 // pinMode(1,  NC);                  // D1 - Arduino Leonardo: Serial1 
 // pinMode(0,  NC);                  // D0 - Arduino Leonardo: Serial1
   
 
 // Initialization SD
    mySerial.print("Initializing SD card...");
    // see if the card is present and can be initialized:
    if (!SD.begin(PIN_SDCARD_SS)) {
      mySerial.println("ERROR: Card failed, or not present");
      while(true)
        blink(PIN_LED_INFO, 250);
    }
    mySerial.println("SD card initialized.");


  // Initialization RTC
    mySerial.print("Initializing RTC...");
    digitalWrite(PIN_LED_INFO, HIGH);
    if (! rtc.begin()) {
      mySerial.println("ERROR: Couldn't find RTC");
      while(true)
        blink(PIN_LED_INFO, 250);
    }
    
    // Set time automatically if needed.
    if (rtc.lostPower()) {
      mySerial.println("RTC lost power, lets set the time!");
      // following line sets the RTC to the date & time this sketch was compiled
      rtc.adjust(DateTime(F(__DATE__), F(__TIME__)));
      // This line sets the RTC with an explicit date & time, for example to set
      // January 21, 2014 at 3am you would call:
      // rtc.adjust(DateTime(2014, 1, 21, 3, 0, 0));
    }
    mySerial.println("rtc initialized.");


  // Initialization Temperature sensor
    mySerial.println("Maxim Integrated DS18B20 Temperature Sensor | cactus.io");
    ds.getSerialNumber();

    
  // Initialization Global variables
    now = future = rtc.now(); // RTC:  Get time for first time
    

  // Pin Initialization
    digitalWrite(PIN_RELAY_1,    RELAY1_STATUS);  // Relé entrada de agua 1 HIGH, ABIERTO
    digitalWrite(PIN_RELAY_2,    RELAY2_STATUS);  // Relé entrada de agua 2 LOW,  CERRADO
    digitalWrite(PIN_LED_STATUS, HIGH);           // Led Verde encendido, todo OK
    digitalWrite(PIN_LED_INFO,   LOW);            // Led Azul apagado,    todo OK


  // System Started!
    mySerial.println("System started!");
    saveEventToSD("System started!");
} // setup()


// Global:
//    variables:  flowRate, flowMilliLitres, totalMilliLitres
void loop() 
{
  float temp_C;    // Sensor: Temperature, value ºC
  float phValue;   // Sensor: Ph, value

  if (itsMesureTime())
  {
    // Medir caudal del sensor YF-S201
    measureFlow();              // AVAILABLE DATA EACH SECOND
    
    // Medir PH del sensor 
    phValue = measurePH();      // AVAILABLE DATA INSTANT
    
    // Leer temperatura del sensor DS18B20
    ds.readSensor();            // AVAILABLE DATA INSTANT
    temp_C = ds.getTemperature_C();


    // Construct Event  to register on microSD card
    String event = "Caudal: ";
    event += String(flowRate);
    event += "L/min, ";
    event += String(flowMilliLitres);
    event += "mL/min";
    event += ",\tCaudal acumulado: ";
    event += String((totalMilliLitres/1000));
    event += "L, ";
    event += String(totalMilliLitres);
    event += "mL";
    event += ",\tPH: ";
    event += String(phValue);
    event += ",\t Temperatura: ";
    event += String(temp_C);
    event += " ºC";

    saveEventToSD(event);
  } 
} // loop()


// Devuelve True si ha pasado el tiempo especificado, False en caso contrario
// Global:
//    constantes: int16_t everyDays, int8_t everyHours, int8_t everyMinutes, int8_t everySeconds
//    variables:  DateTime now, DateTime future, RTC_DS3231 rtc
bool itsMesureTime (void)
{
  now = rtc.now(); // Get the Time

  if (now >= future)
  {
    future = now + TimeSpan(everyDays, everyHours, everyMinutes, everySeconds);
    return true;
  }
    return false;
}


// Global:
//    constantes: PIN_SENSOR_FLOW, flowCalibrationFactor
//    variables:  flowPulseCount, flowRate, flowMilliLitres, totalMilliLitres
void measureFlow ()
{
    // Reset the pulse counter so we can start incrementing again
    flowPulseCount = 0;

    // Note the time this processing pass was executed. Note that because we've
    // disabled interrupts the millis() function won't actually be incrementing right
    // at this point, but it will still return the value it was set to just before
    // interrupts went away.
    unsigned long oldTime = millis();
    
    // The Hall-effect sensor is connected to pin PIN_SENSOR_FLOW which uses interrupt (View Arduino Documentation).
    // Configured to trigger on a FALLING state change (transition from HIGH state to LOW state)
    attachInterrupt(digitalPinToInterrupt(PIN_SENSOR_FLOW), flowPulseCounter, FALLING);

    // Wait for 1 second (measuring sensor)
    while ((millis() - oldTime) <= 1000);
  
    // Disable the interrupt while calculating flow rate and sending the value to the host
    detachInterrupt(digitalPinToInterrupt(PIN_SENSOR_FLOW));

    // Because this loop may not complete in exactly 1 second intervals we calculate
    // the number of milliseconds that have passed since the last execution and use
    // that to scale the output. We also apply the calibrationFactor to scale the output
    // based on the number of pulses per second per units of measure (litres/minute in
    // this case) coming from the sensor.
    flowRate = ((1000.0 / (millis() - oldTime)) * flowPulseCount) / flowCalibrationFactor;
    
    // Divide the flow rate in litres/minute by 60 to determine how many litres have
    // passed through the sensor in this 1 second interval, then multiply by 1000 to
    // convert to millilitres.
    flowMilliLitres = (flowRate / 60) * 1000;
    
    // Add the millilitres passed in this second to the cumulative total
    totalMilliLitres += flowMilliLitres;
} // measureFlow()


// Returns phValue
// Global:
//    constantes: PIN_SENSOR_PH
float measurePH ()
{
    int buf[10],temp;
    float phValue = 0;
    unsigned long int avgValue = 0; //Store the average value of the sensor feedback
    
    // Get 10 sample value from the sensor for smooth the value
    for(int i=0;i<10;i++) 
    { 
      buf[i]=analogRead(PIN_SENSOR_PH);
      delay(10);
    }
    
    // Sort the analog from small to large
    for(int i=0;i<9;i++) 
      for(int j=i+1;j<10;j++)
        if(buf[i]>buf[j]) {
          temp=buf[i];
          buf[i]=buf[j];
          buf[j]=temp;
        }
  
    // Take the average value of 6 center sample
    for(int i=2;i<8;i++) 
      avgValue+=buf[i];
  
    phValue = (float)avgValue*5.0/1024.0/6.0; //convert the analog into millivolt
    phValue = 3.5*phValue;                    //convert the millivolt into pH value
  
    return phValue;
} // measurePH()


// dateTime callback for add date's modification of a file on SDCARD
// Global:
//    variables: DateTime now, rtc
void dateTime(uint16_t* date, uint16_t* time) 
{
     now = rtc.now();
  
    // return date using FAT_DATE macro to format fields
    *date = FAT_DATE(now.year(), now.month(), now.day());
  
    // return time using FAT_TIME macro to format fields
    *time = FAT_TIME(now.hour(), now.minute(), now.second());
}


// Guarda un evento Fecha + Datos en un fichero de la microSD.
// Global: 
//    constantes: String[] daysOfTheWeek,
//    variables:  String date, String event, DateTime now
void saveEventToSD (const String& event)
{
    /* La concatenación de cadenas probablemente desborda la pila de llamadas: no se imprimen las cadenas en Serial */        
    // Construct Date to register on microSD card
    String date = "";
    date += String(now.year());
    date += "/";
    date += String(now.month());
    date += "/";
    date += String(now.day());
    date += " (";
    date += daysOfTheWeek[now.dayOfTheWeek()];
    date += ") ";
    date += String(now.hour());
    date += ":";
    date += String(now.minute());
    date += ":"; 
    date += String(now.second());
  
    // DEBUG Date & Event
    //mySerial.print("saveEventToSD says, date: ");  mySerial.println(date);
    //mySerial.print("saveEventToSD says, event: "); mySerial.println(event);
    
    // Save To SD
    SdFile::dateTimeCallback(dateTime); // https://forum.arduino.cc/index.php?topic=348562.0
    File dataFile = SD.open(fileName, FILE_WRITE);  // class for abstract File inside the microSD card
    while(!dataFile) 
    {
      mySerial.println("saveEventToSD says, file failed to open, retrying in 1 sec...");
      blink(PIN_LED_INFO, 1000);
      
      SdFile::dateTimeCallback(dateTime);
      dataFile = SD.open(fileName, FILE_WRITE);
    }
  
    if (dataFile)
    {
      dataFile.print(date);
      dataFile.print(" - ");
      dataFile.println(event);
      dataFile.close();

      // DEBUG Date + Event
      mySerial.print("saveEventToSD says, savedEvent: ");
      mySerial.print(date);
      mySerial.print(" - ");
      mySerial.println(event);
    }
    else
      mySerial.println("ERROR: esto no debería pasar en la vida, dataFile corrupt");
      

} // saveEventToSD()

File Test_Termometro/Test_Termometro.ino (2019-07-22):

/* Example sketch for Maxim Integrated DS18B20 temperature sensor
   Written by cactus.io, and requires the cactus_io_DS18B20 library.
   This sketch was tested using the Adafruit Prewired DS18B20 Sensor.
   For hookup details using this sensor then visit
   http://cactus.io/hookups/sensors/temperature-humidity/ds18b20/hookup-arduino-to-ds18b20-temperature-sensor
*/
#include "cactus_io_DS18B20.h" 

// Global constants
#define mySerial        Serial  // Switchs between Serial (USB) / Serial1 (Bluetooth) to print data
#define RELAY1_STATUS   HIGH    // HIGH Abierto, LOW Cerrado
#define RELAY2_STATUS   LOW     // HIGH Abierto, LOW Cerrado
#define DELAY_TIME      1000    // ms

#define PIN_LED_INFO    12      // OUTPUT: INFO LED,   HIGH ON, LOW OFF 
#define PIN_LED_STATUS  11      // OUTPUT: STATUS LED, HIGH ON, LOW OFF 
#define PIN_RELAY_1     10      // OUTPUT: LEFT  RELAY, WATER INPUT 1: HIGH OPEN; LOW CLOSED
#define PIN_RELAY_2     9       // OUTPUT: RIGHT RELAY, WATER INPUT 2: HIGH OPEN; LOW CLOSED
#define PIN_SENSOR_TEMP A6      // INPUT: A6 (D4). DS18S20 temperature sensor Analog output to Arduino Analog Input A6 on Digital pin 4
#define PIN_SENSOR_AUX  A8      // INPUT: A8 (D8). Aux sensor analog input for future use.


// Global variables
DS18B20 ds(PIN_SENSOR_TEMP);  // Creates DS18B20 object


void setup(void) 
{
  // Initialize a serial connection for reporting values to the host
    mySerial.begin(115200);
    while(!mySerial);
    mySerial.println("Test_Termometro.ino");


  // Initialize DS18B20 temperature sensor
    mySerial.println("Maxim Integrated DS18B20 Temperature Sensor | cactus.io");
    mySerial.print("DS18B20 Serial Number: ");
    
    ds.readSensor();
    // we pass the serial number byte array into the printSerialNumber function
    printSerialNumber(ds.getSerialNumber());

  
  // Pin initialization
    pinMode(PIN_RELAY_1,      OUTPUT);            // Relé entrada de agua 1
    pinMode(PIN_RELAY_2,      OUTPUT);            // Relé entrada de agua 2
    pinMode(PIN_LED_STATUS,   OUTPUT);            // Led Estado Verde
    pinMode(PIN_LED_INFO,     OUTPUT);            // Led Estado Azul
//  pinMode(PIN_SENSOR_TEMP,  INPUT);             // Sensor TEMP analog input (initialized on DS18B20 constructor)
    pinMode(PIN_SENSOR_AUX,   INPUT);             // Sensor AUX  analog input
    
    digitalWrite(PIN_RELAY_1,    RELAY1_STATUS);  // Relé entrada de agua 1 HIGH, ABIERTO
    digitalWrite(PIN_RELAY_2,    RELAY2_STATUS);  // Relé entrada de agua 2 LOW,  CERRADO
    digitalWrite(PIN_LED_STATUS, HIGH);           // Led Verde encendido, todo OK
    digitalWrite(PIN_LED_INFO,   LOW);            // Led Azul apagado,    todo OK


  // Print relay status
    mySerial.println("Estado inicial de las válvulas:");
    mySerial.print("\tVálvula 1: ");
      if (digitalRead(PIN_RELAY_1) == HIGH)
        mySerial.println("HIGH");
      else
        mySerial.println("LOW");
    mySerial.print("\tVálvula 2: ");
      if (digitalRead(PIN_RELAY_2) == HIGH)
        mySerial.println("HIGH");
      else
        mySerial.println("LOW"); 

    mySerial.println("\n\nTemp (C)\tTemp (F)");
} // setup()


void loop(void) 
{  
    ds.readSensor();
  
    mySerial.print(ds.getTemperature_C()); mySerial.print(" *C\t");
    mySerial.print(ds.getTemperature_F()); mySerial.println(" *F");
  
    delay(DELAY_TIME); // Add some delay just here to slow down the output.
} // loop()


// We call this function to display the DS18B20 serial number. 
// It takes an array of bytes for printing
void printSerialNumber(byte *addr) 
{
    byte i;
  
    for( i = 0; i < 8; i++) {
        mySerial.print("0x");
        if (addr[i] < 16) {
          mySerial.print('0');
        }
        mySerial.print(addr[i], HEX);
        if (i < 7) {
          mySerial.print(", ");
        }
    }
} // printSerialNumber()

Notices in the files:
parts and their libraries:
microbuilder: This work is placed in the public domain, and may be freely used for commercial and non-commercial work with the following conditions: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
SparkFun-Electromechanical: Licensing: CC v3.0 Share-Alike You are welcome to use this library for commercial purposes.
